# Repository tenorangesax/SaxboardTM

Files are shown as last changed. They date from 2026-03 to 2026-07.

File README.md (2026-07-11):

# Saxboard
A custom personalized devboard for me, more on the teaching side for me to understand how the raspberry pi pico boards work and how to do a little basic SMD soldering.

**[WORKING VIDEO DEMO!!](https://youtu.be/bMa3YCjVTW8)**

**Heres the finished product!!!!!!**
rgedge



second
Saxboard
Saxboard_BACK

Schematic:
Screenshot 2026-03-16 at 3 28 55 PM

PCB:

Screenshot 2026-03-21 at 1 45 45 AM
Screenshot 2026-03-21 at 1 45 36 AM
Screenshot 2026-03-21 at 1 45 02 AM
Screenshot 2026-03-21 at 2 00 09 PM
Screenshot 2026-03-21 at 1 59 55 PM
Screenshot 2026-03-21 at 1 59 37 PM

BOM:
[Saxboard - Saxboard.csv.csv](https://github.com/user-attachments/files/26161219/Saxboard.-.Saxboard.csv.csv)
Screenshot 2026-03-21 at 1 59 06 PM

[Uploading JOURNAL (D<!--
  This journal is auto generated by Stasis.
-->

# 4/25/2026 7 PM - Soldering + testing and works!!

_Time spent: 3.5h_

ezgif.com-optimize (2)





rgedge

The buttons arrived, and I got to work soldering!

I had to watch some tutorials on how to SMD solder, and it was hard, but I used my phone to zoom in on the board and got good focus on it to solder.

After soldering the mini 
LED and turtle button, I plugged it in, and it worked! I verifed the button was working because I put it into boot mode.

I ran some test code on it, and it is functional!!!

I tried a lot using Aurdino IDE to make the LED work, then Thonny, but I couldn't work the onboard or external LEDs. 

also while ordering from last few journals i saved money and cut costs a lot, i saved like $50 dollars

Screenshot 2026-04-25 at 2.22.46 PM

also updated github PICS and README to the final pictures too, and made a gif slideshow for showing off the stuff

ezgif.com-optimize

Screenshot 2026-04-25 at 11.05.01 AM

Here are the pictures:

































# 4/22/2026 2 AM - Arrival! (+ testing...)

_Time spent: 1.5h_

The package came today!!!! And it actually works!!!!
I attached some pictures below.

But I'm still waiting on my buttons to come so I can SMD solder them onto the board since the button is required to boot the board so I can program it. It is being read and working though!

I'll update on Friday when I get the button and solder. 



















Screenshot 2026-04-20 at 10.37.45 PM

Screenshot 2026-04-20 at 8.43.30 PM

Screenshot 2026-04-20 at 8.21.18 PM

Screenshot 2026-04-20 at 7.20.05 PM

Screenshot 2026-04-20 at 7.19.46 PM
















# 4/5/2026 3 PM - Even more reordering

_Time spent: 1h_

So there was errors with the specific footprints for C14 and C13, and i backtracked all the way and apparently the tutorial used the wrong footprint, so I had to redo the files and reroute a bit. I also changed C15 and C16 to 33pF instead of 15 because the tutorial never mentioned it but had it in their schematics and its footprints and materials BOM. I had to reassign everything on the JLCPCB ordering page and redo the order,
Screenshot 2026-04-04 at 10.47.37 AM

Screenshot 2026-04-04 at 10.47.47 AM

Screenshot 2026-04-04 at 11.09.23 AM

Screenshot 2026-04-04 at 11.04.04 AM

Screenshot 2026-04-04 at 10.54.55 AM







# 4/4/2026 3 PM - Ordered from JLCPCB

_Time spent: 1.75h_

There was a whole process on ordering it since there was issues with the BOM, but after a lot of searching and asking for help in slack, I realised that the two extra components I added were forcing it to do standard PCBA, in turn, rasing the price to not allow it to do global direct shipping. ($135 -->$45!!)

I also had to redo a part after submitting for review in JLCPCB because of a shortage.

I also ordered the amazon pin headers, I found out after asking some people that you could just split big pin headers into little ones instead of ordering small pin headers.

Screenshot 2026-04-02 at 12.32.08 PM

Screenshot 2026-04-04 at 10.20.01 AM




# 3/21/2026 7 PM - GIT repo, final touches, JCLPCB, and the day my sanity flew away

_Time spent: 3.75h_

I finished the github repo (you can click on the link [https://github.com/tenorangesax/SaxboardTM](url)

i finished the final touches to the pcb, did a lot of research and digging for all the errors i had on jlcpcb for importing the files, and wrapped it all up.

heres just some picture dump, everythings better on  the repo, you should go there instead

***NOTE: THE TRUE REAL BOM IS IN THE GITHUB, THERE WAS ERRORS IMPORTING IT HERE. I NEED J2,J3, and J4, THE PINS TO SOLDER.***

Uploading 1.png...

Uploading 2.png...

Uploading 3.png...

Uploading 4.png...

Uploading 5.png...

Uploading 6.png...

Uploading BOM.png...

Uploading final editor.png...

final editor 2

final editor 3

Final pcb angle view

Final pcb back view

Final pcb front view

Footprints

Saxboard_BACK

Saxboard

schematic











# 3/21/2026 3 PM - PCB He-double hockey sticks

_Time spent: 5.75h_

i didn't sleep at all and finished everything for the pcb

i had to reroute everything and do it like 2 or 3 times till i found an okay spot

here are the pics of some versions

i previously had all the capacitors next to the chip and it made everything difficult

and then there was like 70+ errors when i did the ground pool and had to go through each one.
Screenshot 2026-03-21 at 1.45.45 AM

Screenshot 2026-03-21 at 1.45.36 AM

Screenshot 2026-03-21 at 1.45.02 AM

Screenshot 2026-03-20 at 6.35.36 PM

Screenshot 2026-03-20 at 4.20.34 PM

Screenshot 2026-03-20 at 3.08.10 PM

Screenshot 2026-03-20 at 10.39.25 AM

Screenshot 2026-03-20 at 11.40.43 PM

Saxboard_BACK

Saxboard












# 3/19/2026 2 PM - PCB wiring

_Time spent: 0.6333333333333333h_

today i did some horrible pcb wiring, and i think i need to probably redo everything next time

oh well

heres the stuffs and timelapse
Screenshot 2026-03-19 at 9.58.52 AM

Screenshot 2026-03-19 at 9.59.06 AM




# 3/18/2026 3 PM - PCB Design

_Time spent: 2h_

i designed the pcb,
figured out the problem for the LED is not that big and can *technically* work on online forms and whatnot

i'm 99% sure everything on this is wrong

oh well

heres a failed timelapse (my computer was bugging out)

Screenshot 2026-03-18 at 10.32.18 AM

Screenshot 2026-03-18 at 10.32.44 AM

Screenshot 2026-03-18 at 10.33.13 AM





# 3/18/2026 1 AM - LED "addition"

_Time spent: 3.833333333333333h_

so today from last post i've wanted to add an led to signal different stuff like oh this is on or something embbed in the board.

it was the hardest thing in this project (to date)

i had to research about what leds support what currents, what options i should use, ext. 

i didn't finish it yet, and i'm pretty sure its wrong but heres the stuff.

i'll change it next post maybe bc I asked in slack and dm'd some people to ask

i was experimenting to see if it worked or not with some spare stuff i had and blew up some stuff by accident

the basic problem i had was that the DIN is supposed to be on 37 (GPIO25 on the chip) so i could control color and 3v3 for VDD to be on constantly as a side effect, but I think I have to put VDD on the chip and sacrifice a pin on the rails to control color.











Screenshot 2026-03-17 at 8.40.27 PM








# 3/16/2026 8 PM - Schematic + Errorfixing + Footprint assignments + Research

_Time spent: 5.616666666666667h_

Today i started my first project for Stasis.
I was orignally planning to do the spotify player, but  i decided to do the devboard instead cause it looked cooler

there was a lot of errors and stuff i forgot when cleaning up, and especially the crystal issue

i looked it up and did some searching, apparently for kicad, they had an update causing the crystal to have 3 pins instead of four, but its fine since the 4th is just another ground like the second pin.

i attached images of the jlcpcb actual crystal, my schematics, and the footprint assignments

i might add an led and maybe a resistor would be a good idea.

Screenshot 2026-03-16 at 3.28.55 PM

Screenshot 2026-03-16 at 3.29.29 PM

Screenshot 2026-03-16 at 3.30.53 PM




EVBOARD).md…]()

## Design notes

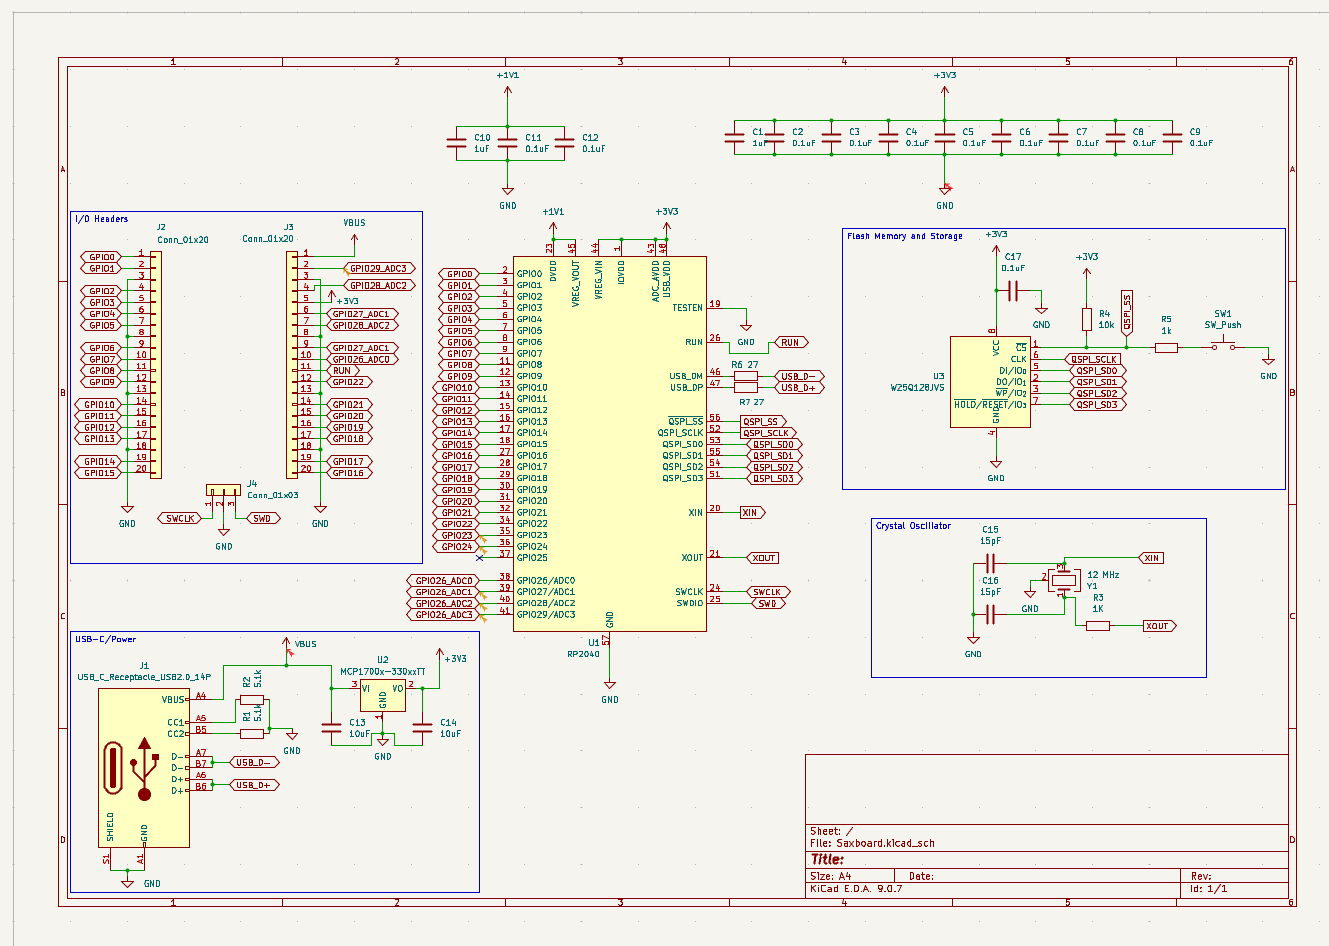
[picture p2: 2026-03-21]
Pictures/schematic.png

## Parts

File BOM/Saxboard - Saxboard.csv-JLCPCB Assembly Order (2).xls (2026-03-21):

JLCPCB BOM Tool - BOM Matching
BOM name：Saxboard - Saxboard.csv-JLCPCB Assembly Order.xlsx |  |  | Download Time：2026-03-22 04:21:09 |  |  |  | * Our matching results are updated in real-time, but stock and prices may change. If it's been over 24 hours, please re-match before placing your order.
PCB Assembled Qty：5 |  |  | Est. Total Price：19.1754
Your BOM |  |  |  |  | Matched Parts |  |  |  |  |  |  | Order Information
Top Designator | Bottom Designator | Comment | Footprint | JLCPCB Part # | Matches | Part # | Manufacturer | Footprint | Description | Category | Warning | JLCPCB Part # | Product link | Lib Type | Qty | Source | Total Price ($)
C1,C10 |  | 1uF | C_0402_1005Metric |  | Select by Customer | CL05A105KA5NQNC | Samsung Electro-Mechanics | 0402 | 1uF 25V X5R ±10% 0402 Multilayer Ceramic Capacitors MLCC - SMD/SMT ROHS | Multilayer Ceramic Capacitors MLCC - SMD/SMT |  | C52923 | https://jlcpcb.com/partdetail/53938-CL05A105KA5NQNC/C52923 | Basic | 20 | 20 JLCPCB | 0.08
C5,C7,C11,C6,C3,C12,C9,C2,C4,C17,C8 |  | 0.1uF | C_0402_1005Metric |  | Select by Customer | CL05B104KO5NNNC | Samsung Electro-Mechanics | 0402 | 100nF 16V X7R ±10% 0402 Multilayer Ceramic Capacitors MLCC - SMD/SMT ROHS | Multilayer Ceramic Capacitors MLCC - SMD/SMT | 1.The comment (CL05B104KO5NNNC) of this part does not match the one (0.1uF) provided in your BOM. Please confirm; | C1525 | https://jlcpcb.com/partdetail/1877-CL05B104KO5NNNC/C1525 | Basic | 65 | 65 JLCPCB | 0.0845
C14,C13 |  | 10uF | C_0402_1005Metric |  | Select by Customer | CL10A106KP8NNNC | Samsung Electro-Mechanics | 0603 | 10V 10uF X5R ±10% 0603 Multilayer Ceramic Capacitors MLCC - SMD/SMT ROHS | Multilayer Ceramic Capacitors MLCC - SMD/SMT |  | C19702 | https://jlcpcb.com/partdetail/20411-CL10A106KP8NNNC/C19702 | Basic | 20 | 20 JLCPCB | 0.144
C16,C15 |  | 15pF | C_0402_1005Metric |  | Select by Customer | 0402CG150J500NT | FH (Guangdong Fenghua Advanced Tech) | 0402 | 15pF 50V C0G ±5% 0402 Multilayer Ceramic Capacitors MLCC - SMD/SMT ROHS | Multilayer Ceramic Capacitors MLCC - SMD/SMT |  | C1548 | https://jlcpcb.com/partdetail/1900-0402CG150J500NT/C1548 | Basic | 20 | 20 JLCPCB | 0.026
D2 |  | SK6812MINI | LED_SK6812MINI_PLCC4_3.5x3.5mm_P1.75mm |  | Select by Customer | SK6812MINI-E | OPSCO Optoelectronics | SMD | -40℃~+85℃ 0.6mA 1.78mm 120° 1kHz 2.8mm 2000V 3.2mm 3.7V~5.5V 800Kbit/s G:815mcd~1275mcd、B:120mcd~240mcd、R:160mcd~320mcd R:620nm~625nm、G:515nm~525nm、B:460nm~470nm Semi-transparent lens SMD RGB LEDs(Built-in IC) ROHS | RGB LEDs(Built-In IC) | 1.The comment (SK6812MINI-E) of this part does not match the one (SK6812MINI) provided in your BOM. Please confirm; | C5149201 | https://jlcpcb.com/partdetail/OPSCOOptoelectronics-SK6812MINIE/C5149201 | Extended | 7 | 7 JLCPCB | 0.6398
J1 |  | USB_C_Receptacle_USB2.0_14P | USB_C_Receptacle_HRO_TYPE-C-31-M-12 |  | Select by Customer | TYPE-C-31-M-12 | Korean Hroparts Elec | SMD | -30℃~+80℃ 1 10,000 cycles 16P 20V 5A 7.35mm Female Surface Mount, Right Angle Type-C SMD USB Connectors ROHS | USB Connectors |  | C165948 | https://jlcpcb.com/partdetail/Korean_HropartsElec-TYPE_C_31_M12/C165948 | Extended | 5 | 5 JLCPCB | 0.906
J2,J3 |  | Conn_01x20 | PinHeader_1x20_P2.54mm_Vertical |  | Select by Customer | 2.54-1*20P直针 | BOOMELE(Boom Precision Elec) | 插件,P=2.54mm | -40℃~+105℃ 1 1x20P 2.54mm 20P 3A Black Brass Pin Header Through Hole Plugin,P=2.54mm Pin Headers ROHS | Pin Headers |  | C50981 | https://jlcpcb.com/partdetail/51993-2_54_1_20P/C50981 | Extended | 10 | 10 JLCPCB | 0.943
J4 |  | Conn_01x03 | PinHeader_1x03_P2.54mm_Vertical |  | Select by Customer | 2.54-1*3P针 | BOOMELE(Boom Precision Elec) | 插件,P=2.54mm | -40℃~+105℃ 1 1x3P 2.54mm 2.5mm 3A 3P 3mm 6mm Black Brass Gold Pin Header Through Hole Plugin,P=2.54mm Pin Headers ROHS | Pin Headers |  | C49257 | https://jlcpcb.com/partdetail/50265-2_54_1_3P/C49257 | Extended | 7 | 7 JLCPCB | 0.1421
R1,R2 |  | 5.1k | R_0402_1005Metric |  | Select by Customer | 0402WGF5101TCE | UNI-ROYAL(Uniroyal Elec) | 0402 | -55℃~+155℃ 5.1kΩ 50V 62.5mW Thick Film Resistor ±1% ±100ppm/℃ 0402 Chip Resistor - Surface Mount ROHS | Chip Resistor - Surface Mount |  | C25905 | https://jlcpcb.com/partdetail/26648-0402WGF5101TCE/C25905 | Basic | 20 | 20 JLCPCB | 0.016
R3 |  | 1K | R_0402_1005Metric |  | Select by Customer | 0402WGF1001TCE | UNI-ROYAL(Uniroyal Elec) | 0402 | -55℃~+155℃ 1kΩ 50V 62.5mW Thick Film Resistor ±1% ±100ppm/℃ 0402 Chip Resistor - Surface Mount ROHS | Chip Resistor - Surface Mount | 1.The comment (0402WGF1001TCE) of this part does not match the one (1K) provided in your BOM. Please confirm; 2.Multiple lines in the BOM have been matched to the same part. Please check if the matching is correct. ; | C11702 | https://jlcpcb.com/partdetail/12256-0402WGF1001TCE/C11702 | Basic | 20 | 20 JLCPCB | 0.014
R5 |  | 1k | R_0402_1005Metric |  | Select by Customer | 0402WGF1001TCE | UNI-ROYAL(Uniroyal Elec) | 0402 | -55℃~+155℃ 1kΩ 50V 62.5mW Thick Film Resistor ±1% ±100ppm/℃ 0402 Chip Resistor - Surface Mount ROHS | Chip Resistor - Surface Mount | 1.The comment (0402WGF1001TCE) of this part does not match the one (1k) provided in your BOM. Please confirm; 2.Multiple lines in the BOM have been matched to the same part. Please check if the matching is correct. ; | C11702 | https://jlcpcb.com/partdetail/12256-0402WGF1001TCE/C11702 | Basic | 20 | 20 JLCPCB | 0.014
R4 |  | 10k | R_0402_1005Metric |  | Select by Customer | 0402WGF1002TCE | UNI-ROYAL(Uniroyal Elec) | 0402 | -55℃~+155℃ 10kΩ 50V 62.5mW Thick Film Resistor ±1% ±100ppm/℃ 0402 Chip Resistor - Surface Mount ROHS | Chip Resistor - Surface Mount | 1.The comment (0402WGF1002TCE) of this part does not match the one (10k) provided in your BOM. Please confirm; | C25744 | https://jlcpcb.com/partdetail/26487-0402WGF1002TCE/C25744 | Basic | 20 | 20 JLCPCB | 0.016
R6,R7 |  | 27 | R_0402_1005Metric |  | Select by Customer | 0402WGF270JTCE | UNI-ROYAL(Uniroyal Elec) | 0402 | -55℃~+155℃ 27Ω 50V 62.5mW Thick Film Resistor ±1% ±100ppm/℃ 0402 Chip Resistor - Surface Mount ROHS | Chip Resistor - Surface Mount | 1.The comment (0402WGF270JTCE) of this part does not match the one (27) provided in your BOM. Please confirm; | C25100 | https://jlcpcb.com/partdetail/25843-0402WGF270JTCE/C25100 | Extended | 22 | 22 JLCPCB | 0.0176
SW1 |  | SW_Push | SW_Push_SPST_NO_Alps_SKRK |  | Select by Customer | TS-1088-AR02016 | XUNPU | SMD,4x3mm | -30℃~+80℃ 1.6N 100,000 cycles 12V 2mm 3mm 4mm 50mA Black Round Button SMD(SMT) Tab SPST Surface Mount,Vertical Without Bracket SMD,4x3mm Tactile Switches ROHS | Tactile Switches |  | C720477 | https://jlcpcb.com/partdetail/XUNPU-TS_1088AR02016/C720477 | Basic | 9 | 9 JLCPCB | 0.4815
U1 |  | RP2040 | QFN-56-1EP_7x7mm_P0.4mm_EP3.2x3.2mm |  | Select by Customer | RP2040 | Raspberry Pi | LQFN-56(7x7) | 12bit 133MHz 30 LQFN-56(7x7) Microcontrollers (MCU/MPU/SOC) ROHS | Microcontrollers (MCU/MPU/SOC) |  | C2040 | https://jlcpcb.com/partdetail/RaspberryPi-RP2040/C2040 | Extended | 5 | 5 JLCPCB | 4.8295
U2 |  | MCP1700x-330xxTT | SOT-23 |  | Select by Customer | MCP1700T-3302E/TT | Microchip Tech | SOT-23 | -40℃~+125℃@(Tj) 1 1.6uA 178mV@(250mA) 250mA 3.3V 44dB@(100Hz) 6V Fixed Over Temperature Protection、Short Circuit Protection Positive SOT-23 Voltage Regulators - Linear, Low Drop Out (LDO) Regulators ROHS | Voltage Regulators - Linear, Low Drop Out (LDO) Regulators |  | C39051 | https://jlcpcb.com/partdetail/MicrochipTech-MCP1700T_3302ETT/C39051 | Extended | 5 | 5 JLCPCB | 1.837
U3 |  | W25Q16JVUXIQ | Winbond_USON-8-1EP_3x2mm_P0.5mm_EP0.2x1.6mm |  | Select by Customer | W25Q16JVUXIQ | Winbond Elec | USON-8-EP(2x3) | -40℃~+85℃ 100,000 cycles 10uA 133MHz 16Mbit 2.7V~3.6V 20 Years 3ms SPI USON-8-EP(2x3) NOR FLASH ROHS | NOR FLASH |  | C2843335 | https://jlcpcb.com/partdetail/WinbondElec-W25Q16JVUXIQ/C2843335 | Extended | 5 | 5 JLCPCB | 8.331
Y1 |  | 12MHz | Crystal_SMD_3225-4Pin_3.2x2.5mm |  | Select by Customer | X322512MSB4SI | YXC Crystal Oscillators | SMD3225-4P | -40℃~+85℃ 12MHz 20pF Crystal Oscillator ±10ppm ±20ppm SMD3225-4P Crystals ROHS | Crystals |  | C9002 | https://jlcpcb.com/partdetail/YXC_CrystalOscillators-X322512MSB4SI/C9002 | Basic | 9 | 9 JLCPCB | 0.6534

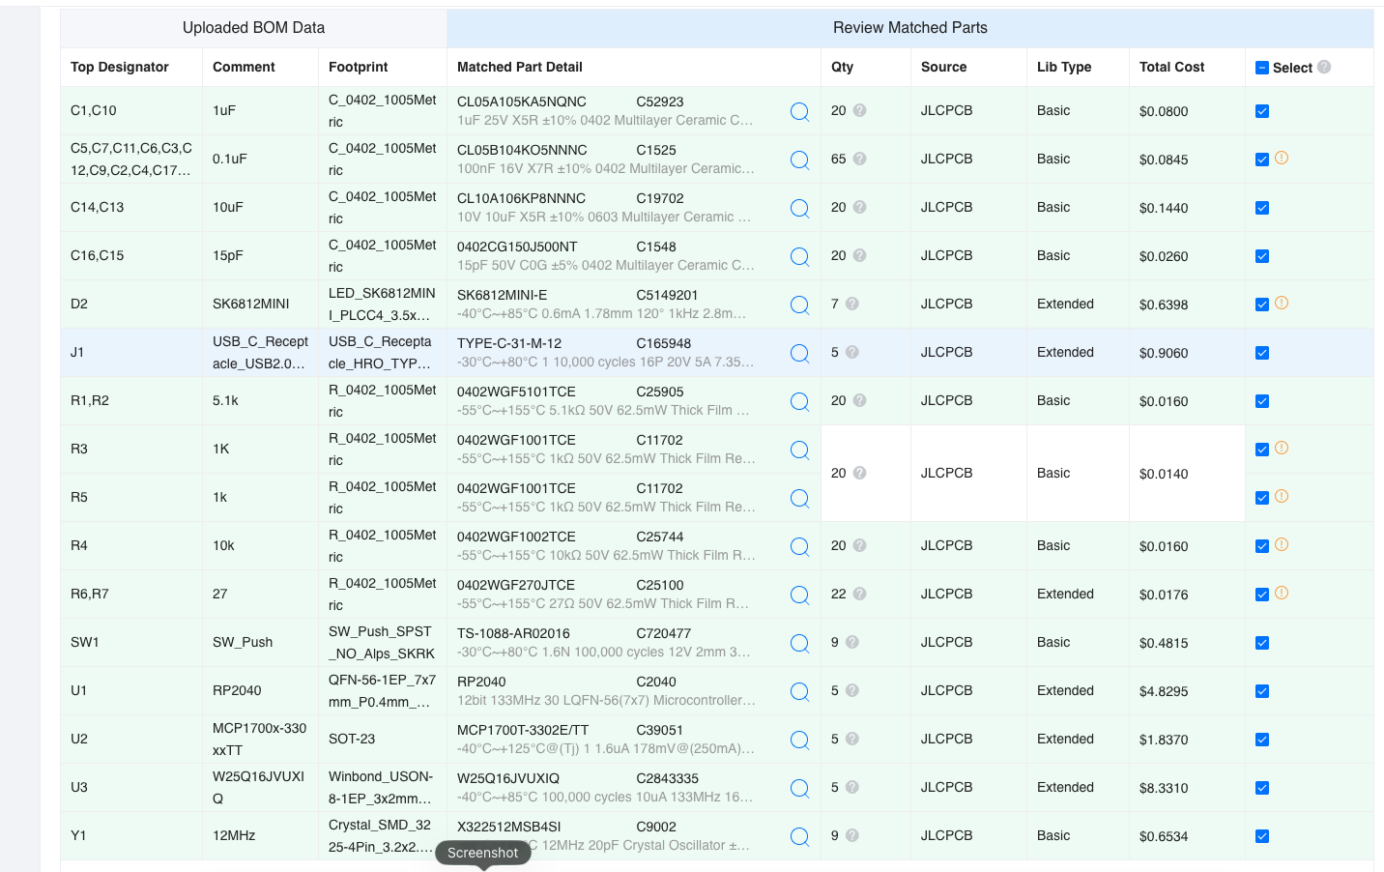
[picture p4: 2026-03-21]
Pictures/BOM.png

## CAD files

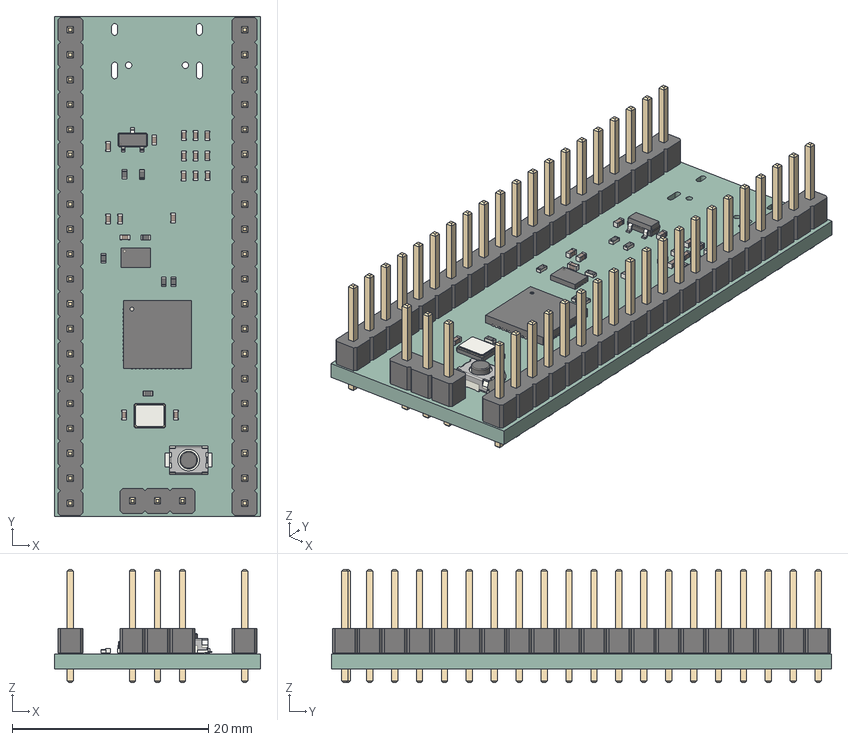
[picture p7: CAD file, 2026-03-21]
PCB/Saxboard.step
21.0 x 51.0 x 11.5 mm
C_0402_1005Metric x 17
Crystal_SMD_3225-4Pin_3.2x2.5mm
PinHeader_1x20_P2.54mm_Vertical x 2
Winbond_USON-8-1EP_3x2mm_P0.5mm_EP0.2x1.6mm
R_0402_1005Metric x 7
SOT-23
PinHeader_1x03_P2.54mm_Vertical
SW_Push_SPST_NO_Alps_SKRK
QFN-56-1EP_7x7mm_P0.4mm_EP3.2x3.2mm
Saxboard_PCB

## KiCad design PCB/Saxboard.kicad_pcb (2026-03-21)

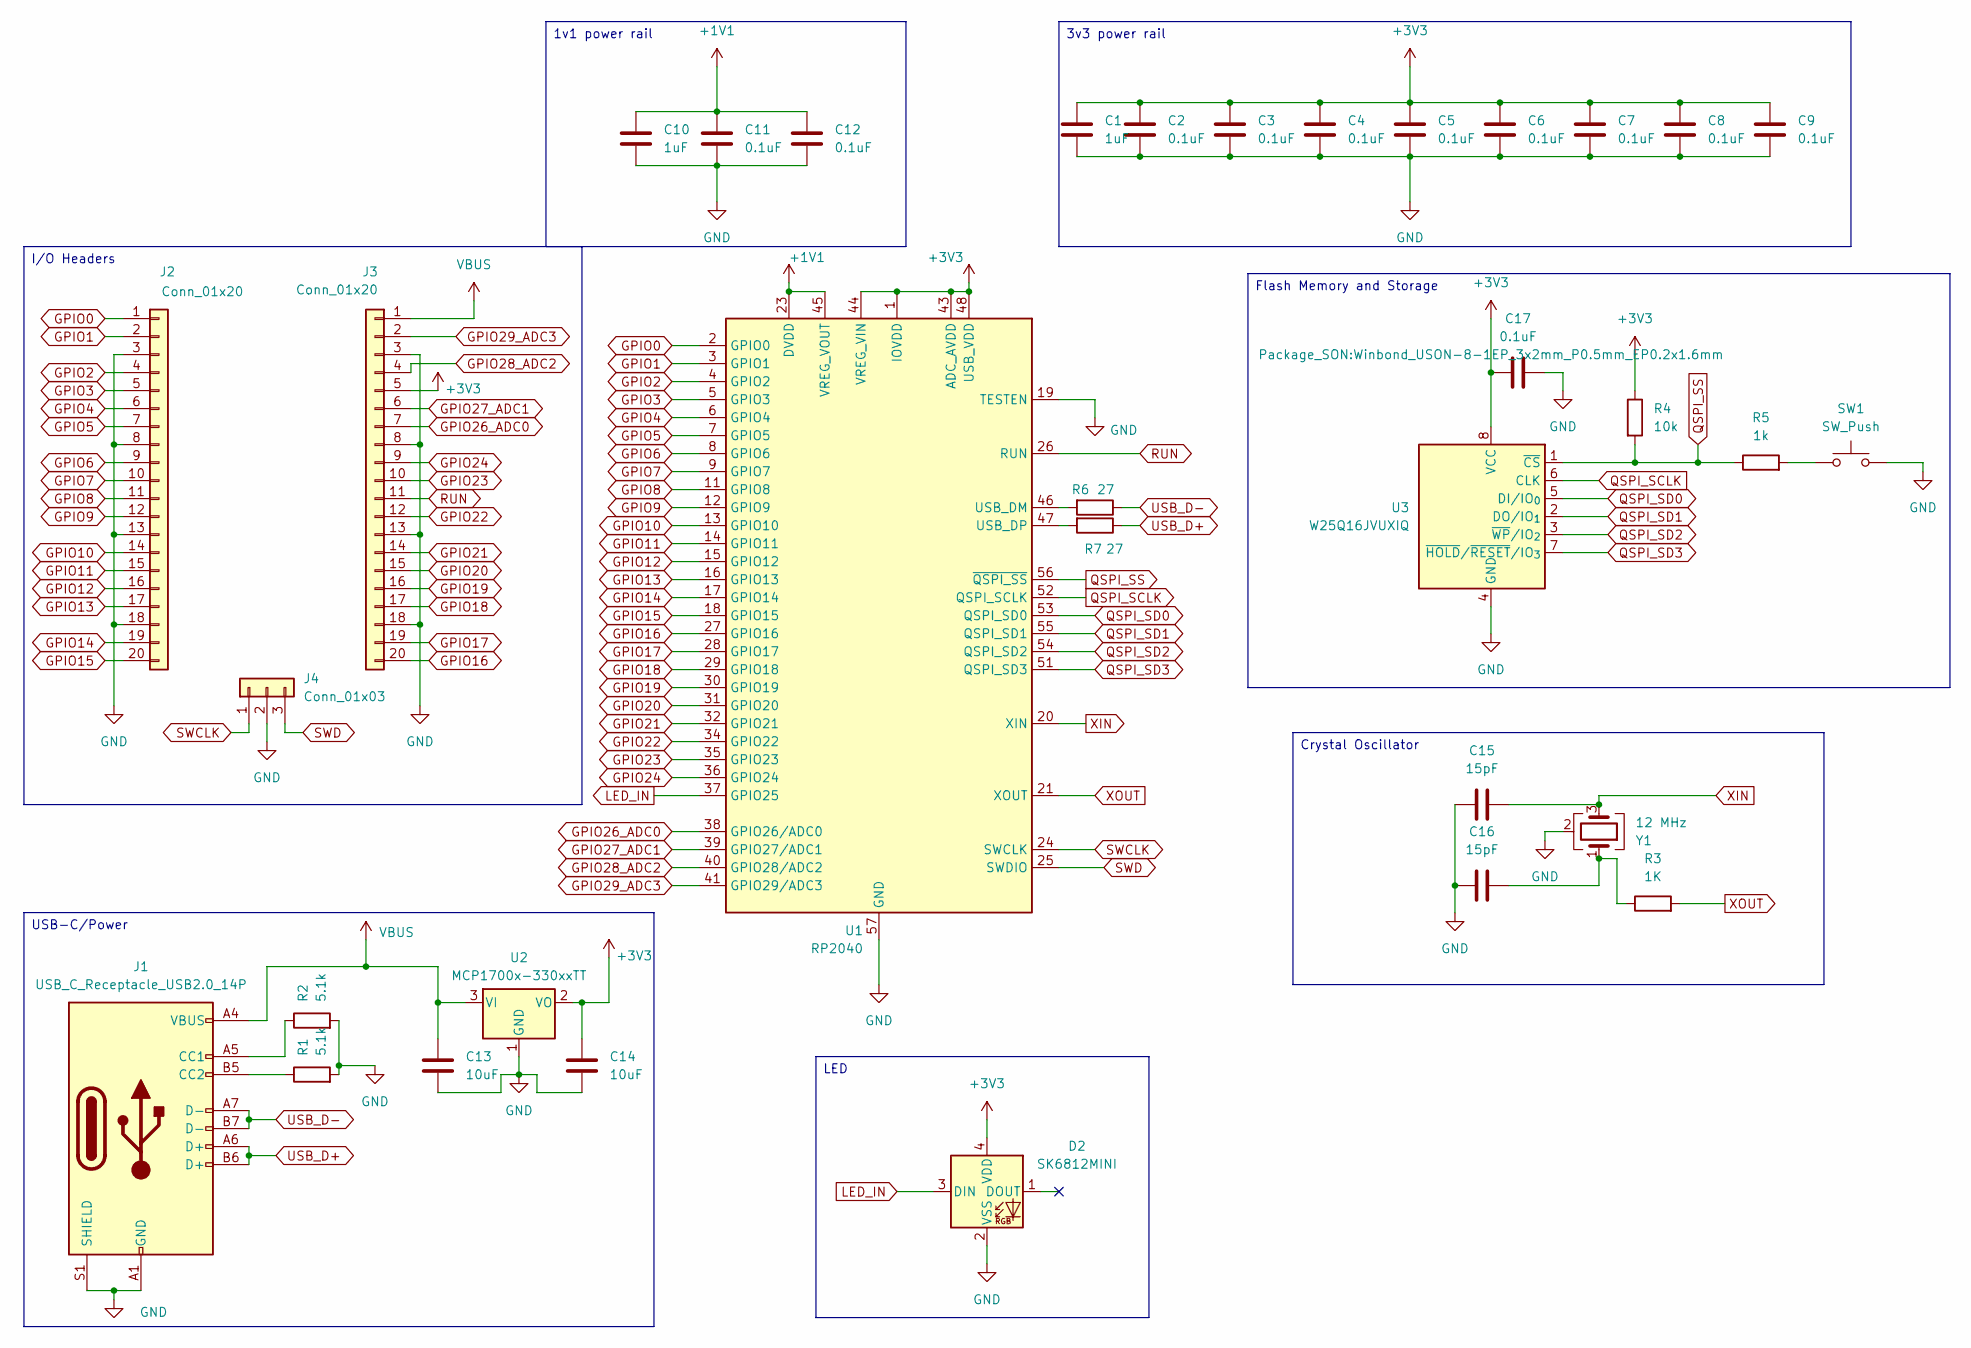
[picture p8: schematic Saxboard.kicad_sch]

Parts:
C1, C10: 1uF; C_0402_1005Metric
C2, C3, C4, C5, C6, C7, C8, C9, C11, C12, C17: 0.1uF; C_0402_1005Metric
C13, C14: 10uF; C_0402_1005Metric
C15, C16: 15pF; C_0402_1005Metric
D2: SK6812MINI; LED_SK6812MINI_PLCC4_3.5x3.5mm_P1.75mm
J1: USB_C_Receptacle_USB2.0_14P; USB_C_Receptacle_HRO_TYPE-C-31-M-12
J2, J3: Conn_01x20; PinHeader_1x20_P2.54mm_Vertical
J4: Conn_01x03; PinHeader_1x03_P2.54mm_Vertical
R1, R2: 5.1k; R_0402_1005Metric
R3: 1K; R_0402_1005Metric
R4: 10k; R_0402_1005Metric
R5: 1k; R_0402_1005Metric
R6, R7: 27; R_0402_1005Metric
SW1: SW_Push; SW_Push_SPST_NO_Alps_SKRK
U1: RP2040; QFN-56-1EP_7x7mm_P0.4mm_EP3.2x3.2mm
U2: MCP1700x-330xxTT; SOT-23
U3: W25Q16JVUXIQ; Winbond_USON-8-1EP_3x2mm_P0.5mm_EP0.2x1.6mm
Y1: 12 MHz; Crystal_SMD_3225-4Pin_3.2x2.5mm

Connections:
+1V1: C10.1, C11.1, C12.1, U1.23 (DVDD), U1.45 (VREG_VOUT), U1.50 (DVDD)
+3V3: C1.1, C2.1, C3.1, C4.1, C5.1, C6.1, C7.1, C8.1, C9.1, C14.1, C17.1, D2.4 (VDD), J3.5, R4.1, U1.1 (IOVDD), U1.10 (IOVDD), U1.22 (IOVDD), U1.33 (IOVDD), U1.42 (IOVDD), U1.43 (ADC_AVDD), U1.44 (VREG_VIN), U1.48 (USB_VDD), U1.49 (IOVDD), U2.2 (VO), U3.8 (VCC)
GND: C1.2, C2.2, C3.2, C4.2, C5.2, C6.2, C7.2, C8.2, C9.2, C10.2, C11.2, C12.2, C13.2, C14.2, C15.1, C16.1, C17.2, D2.2 (VSS), J1.A1 (GND), J1.A12 (GND), J1.B1 (GND), J1.B12 (GND), J1.S1 (SHIELD), J2.3, J2.8, J2.13, J2.18, J3.3, J3.8, J3.13, J3.18, J4.2, R1.2, R2.2, SW1.2, U1.19 (TESTEN), U1.57 (GND), U2.1 (GND), U3.4 (GND), Y1.2 (G), Y1.4 (G)
GPIO0: J2.1, U1.2 (GPIO0)
GPIO1: J2.2, U1.3 (GPIO1)
GPIO2: J2.4, U1.4 (GPIO2)
GPIO3: J2.5, U1.5 (GPIO3)
GPIO4: J2.6, U1.6 (GPIO4)
GPIO5: J2.7, U1.7 (GPIO5)
GPIO6: J2.9, U1.8 (GPIO6)
GPIO7: J2.10, U1.9 (GPIO7)
GPIO8: J2.11, U1.11 (GPIO8)
GPIO9: J2.12, U1.12 (GPIO9)
GPIO10: J2.14, U1.13 (GPIO10)
GPIO11: J2.15, U1.14 (GPIO11)
GPIO12: J2.16, U1.15 (GPIO12)
GPIO13: J2.17, U1.16 (GPIO13)
GPIO14: J2.19, U1.17 (GPIO14)
GPIO15: J2.20, U1.18 (GPIO15)
GPIO16: J3.20, U1.27 (GPIO16)
GPIO17: J3.19, U1.28 (GPIO17)
GPIO18: J3.17, U1.29 (GPIO18)
GPIO19: J3.16, U1.30 (GPIO19)
GPIO20: J3.15, U1.31 (GPIO20)
GPIO21: J3.14, U1.32 (GPIO21)
GPIO22: J3.12, U1.34 (GPIO22)
GPIO23: J3.10, U1.35 (GPIO23)
GPIO24: J3.9, U1.36 (GPIO24)
GPIO26_ADC0: J3.7, U1.38 (GPIO26/ADC0)
GPIO27_ADC1: J3.6, U1.39 (GPIO27/ADC1)
GPIO28_ADC2: J3.4, U1.40 (GPIO28/ADC2)
GPIO29_ADC3: J3.2, U1.41 (GPIO29/ADC3)
LED_IN: D2.3 (DIN), U1.37 (GPIO25)
unnamed: C16.2, R3.1, Y1.1
unnamed: J1.A5 (CC1), R2.1
unnamed: J1.B5 (CC2), R1.1
unnamed: R5.2, SW1.1
unnamed: R6.2, U1.46 (USB_DM)
unnamed: R7.2, U1.47 (USB_DP)
QSPI_SCLK: U1.52 (QSPI_SCLK), U3.6 (CLK)
QSPI_SD0: U1.53 (QSPI_SD0), U3.5 (DI/IO_{0})
QSPI_SD1: U1.55 (QSPI_SD1), U3.2 (DO/IO_{1})
QSPI_SD2: U1.54 (QSPI_SD2), U3.3 (~WP/IO_{2})
QSPI_SD3: U1.51 (QSPI_SD3), U3.7 (~HOLD/~RESET/IO_{3})
QSPI_SS: R4.2, R5.1, U1.56 (~QSPI_SS), U3.1 (~CS)
RUN: J3.11, U1.26 (RUN)
SWCLK: J4.1, U1.24 (SWCLK)
SWD: J4.3, U1.25 (SWDIO)
USB_D+: J1.A6 (D+), J1.B6 (D+), R7.1
USB_D-: J1.A7 (D-), J1.B7 (D-), R6.1
VBUS: C13.1, J1.A4 (VBUS), J1.A9 (VBUS), J1.B4 (VBUS), J1.B9 (VBUS), J3.1, U2.3 (VI)
XIN: C15.2, U1.20 (XIN), Y1.3
XOUT: R3.2, U1.21 (XOUT)

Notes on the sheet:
3v3 power rail
Crystal Oscillator
USB-C/Power
LED
1v1 power rail
Flash Memory and Storage
I/O Headers

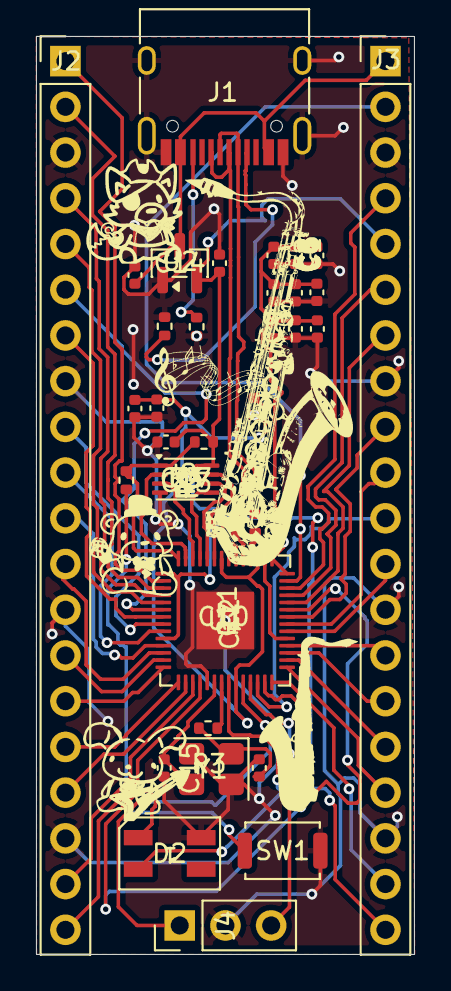
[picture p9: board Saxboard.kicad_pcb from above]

Board: 2 copper layers, 21.0 x 51.0 mm, 34 parts (0 on the bottom side), 53 nets.

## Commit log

2026-03-21 Enhance README with project details and images
    Added images and detailed information about the Saxboard project, including schematic, PCB, BOM, and a picture dump.
2026-03-21 Enhance README formatting and add BOM images
    Updated formatting for emphasis and added images to the BOM section.
